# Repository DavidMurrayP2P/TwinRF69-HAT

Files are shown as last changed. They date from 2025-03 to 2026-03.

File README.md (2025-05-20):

# TwinRF69: A new wireless inteface option for the Raspberry Pi (Work in Progress)

The Twin RF69 project aims to extend the wireless capabilities of the Raspberry Pi ecosystem into two different frequencies in the sub 1GHz band. The goal of this is to provide a wireless mesh based alternative to WiFi that utilises longer range, lower power but can still talk IP. I've decided to go down the path of creating dedicated hardware after exploring all the viable options. You can read through and look at my dive into the [wireless interface options](WIRELESS_INTERFACE_RESEARCH.md) for the Raspberry Pi.

The current state of this project is that the hardware design and the code in this repository works. We can successfully send packets on the 915MHz and 433MHz band, and the range exceeds that of WiFi. The interfaces do not yet support IP however.

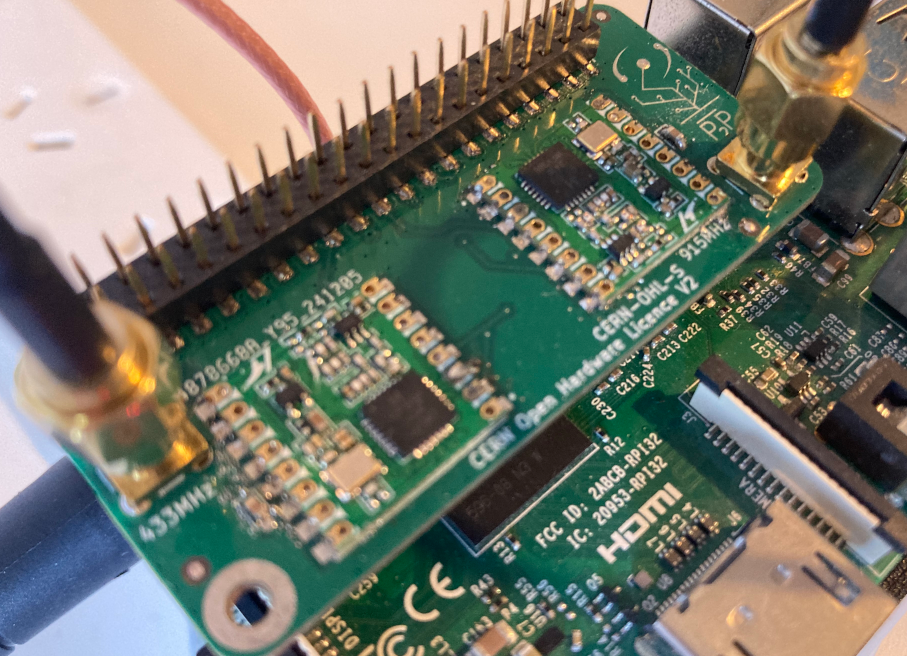
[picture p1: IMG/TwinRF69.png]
 <p style="text-align:center; font-style:italic;">A prototype of the TwinRF69</p>

You can find the user docs, showing you how to get started with the TwinRF69, and the design decisions around the board here:
* [USERDOCS](USERDOCS.md) 
* [DESIGN_AND_DECISIONS](DESIGN_AND_DECISIONS.md)

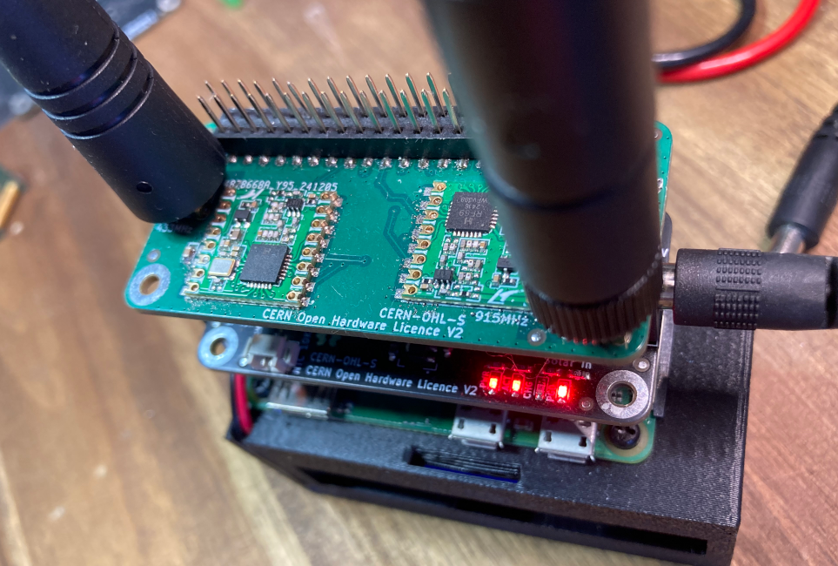
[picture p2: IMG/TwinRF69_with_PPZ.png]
 <p style="text-align:center; font-style:italic;">This project works well with the [Photon Power Zero](https://www.youtube.com/watch?v=qGwqMnN81YI). Both the Photon Power Zero and the TwinRF69  operate as stackable hearders for the Raspberry Pi. This is designed around low power and potentially solar, battery operation and integration with the Photon Power Zero. You can find out more about hit project at the [Photon Power Zero Github](https://github.com/DavidMurrayP2P/PhotonPowerZero/). 

As an open-source project, you can find the code for the Twin RF69, the Kicad PCB files and the FDM 3D printing files below
* [Code](Code)
* [PCBs](PCBs)
* [FDM (3D Print Files)](FDM)

You can find some mounts for Raspberry Pi that include spots for SMA pigtails and power supplies in [FDM (3D Print Files)](FDM)

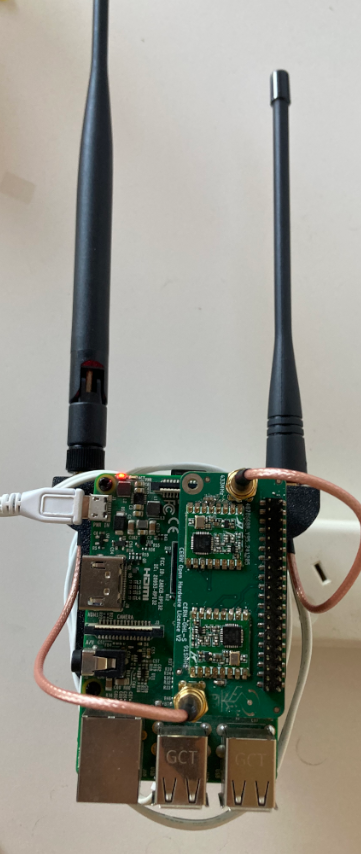
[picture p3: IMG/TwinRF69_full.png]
 <p style="text-align:center; font-style:italic;">A prototype of the TwinRF69</p>

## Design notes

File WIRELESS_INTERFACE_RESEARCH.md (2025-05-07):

# WIRELESS INTERFACE OPTIONS

### This page is incomplete and is a work in progress

This page documents the different Wireless interface options that are avaliable on the Raspberry Pi, obviously going beyond the inbuilt WiFi and Bluetooth. 

As you know the goal of this project is to make it as easy as possible to deply outdoor computing. We want to be able to easily deploy outdoor single board computers and have sensors or cameras report information back. A large comonent of this is networking and having wireless interfaces that ensure that we can collect the data over a wireless interface. 

This page reviews the options and provides the code to make them work. The goal of this project is to make it as easy as possible. We want the network interface to be low power, with a goal of the network interface is to use less than 5V x 0.1 Amps 0.5W on standby and 5V x 0.15 Amps 0.75W while transmitting. With the Raspberry Pi Zero, this means that we are aming fro less than 5v 0.25 Amps total which is 1.25 Watts in total. Going beyond this we will have implications for batteries and solar pannels.

We also want this to be easy. So Ideally, this should be easy to connect to an IP or IPv6 network. I think that the ideal technology in this space, will likely be 6LowPAN. While this has historically been used for 802.15.4 networks it can be used with sme of the Sub-GHz ISM band radios.

Finally, the solution should cost under 40USD. This is not a hard requirement, initially higher costs are tolerable if there is the opportunity for reduced costs in the future with volume.

Speeds should be in the 50-200Kb/s range. The goal is not to stream live video, but we should be at least able to move a 350KB image within 60 seconds. So 350KB is 2800 bytes. If the link supports 50Kb/s then 2800/50 = 56 seconds.

The following is an attempt to evaluate what is currently out there on the market.

## Design Criteria

The goal of this is to provide you with the information you might need if you are deploying a low power solar powered Rasberry Pi Zero. As you can see below, the Raspberry Pi Zero runs at 5V and 0.1 amps which is 0.5W when idle. The design criteria is to stay under 0.2 Amps when Idle and under 0.25 amps when transmitting data. These are my goals for heat and battery life reasons. Be aware that in the [Reducing Energy Consumption](REDUCING_ENERGY_CONSUMPTION.md) document, the power consumption of the Pi Zero 2W was about 25% higher at idle speeds. These are very much ballpark numbers however.

# Options

 - [Cellular Options](#Cellular-Options)
	- [The SIM7600X 4G HAT](#the-sim7600x-4g-hat)
    - [SIMCOM-7020E](#SIMCOM-7020E) NB-IoT
    - [SIMCOM-A7670SA](#SIMCOM-A7670SA) LTE Cat1 Module

 - [LoRaWAN options](#LoRaWAN-Options)
   - [RAK2245](#RAK2245) - Pi HAT 8 Channel LoRaWAN module SX1301
   - [RAK811](#RAK811) LoRaWan End Device

 - [Other Options](#Other-Options)
    - [NRF24](#NRF24)
    - [RFM69HCW](#RFM69HCW)

## Cellular Options

### The SIM7600X 4G HAT

The SIM7600X 4G HAT is a great fit for the Pi. The form factor is great. It appears to work over USB, using spring pins to hit VCC, GND, D+ and D-. You can see the idle power consumption as well as the power consumption under load below. This is a very good module however the price as well as the power consumption are both highert than I would like to see.

Here is the idle power consumption:

Title <p style="text-align:center; font-style:italic;">Raspberry Pi Zero Rough Idle power conspmption </p

#### Config

Check if the Modem is Detected:

```
sudo mmcli -L
```

Enable and Configure the Modem:

```
sudo mmcli -m 0 --enable
sudo mmcli -m 0 --simple-connect="apn=YOUR_APN"
Replace YOUR_APN with your carrier's APN.
```

You can create a new connection using NetworkManager.

```
sudo nmcli connection add type gsm ifname cdc-wdm0 con-name gsm connection.autoconnect yes apn YOUR_APN
```
Connect to the Network:
```
sudo nmcli connection up gsm
```

Once connected, you should see the wwan0 interface with an IP address like below:

Title <p style="text-align:center; font-style:italic;">Raspberry Pi Zero Rough Idle power conspmption </p>

This is the power consumption when lightly loaded.

Title <p style="text-align:center; font-style:italic;">Raspberry Pi Zero Rough Idle power conspmption </p>

Note that this is just a lot higher than we would ideally like to see. 

Title <p style="text-align:center; font-style:italic;">Raspberry Pi Zero Rough Idle power conspmption </p>

### SIMCOM-7020E

This looked exceptionally convenient as the form factor was already Raspberry Pi Zero sided and the headers matched up, eliminating any wiring. I had hoped that this might just work with regular sim card but unfortuately this needs an NB-IoT specialised sim card.

Title <p style="text-align:center; font-style:italic;">The power consumption of the SIMCOM-7020E</p>

### SIMCOM-A7670SA 
##### LTE Cat1 Module

I was excited to try this device because it was sold as supporting LTE Cat 1, but this did not recognise a regular sim. I will keep investigating this module but an initial look did not seem promising. This also only supported serial communications.

This did not work with my regular cheap phone sim.

Setup is pretty simple

```sudo raspi-config```

Navigate to Interfacing Options -> Serial. When prompted, select No to disable the serial console, then select Yes to enable the serial port hardware.

```sudo apt install minicom```

On the serial, try a:

```AT```

Then test if a SIM card has been inserted and detected:

```AT+CPIN?```

This will confirm that the modem is responding. Then: 

```AT+CGDCONT=1,"IP","telstra.m2m"```

Enable the network connection:

```AT+CIICR```

Get the IP address assigned to the module:

```AT+CIFSR```

![Alt text](img/Wireless_Interfaces/SIMA7670SA.png?raw=true "Title") <p style="text-align:center; font-style:italic;">The power consumption of the SIMCOM-A7670SA </p>

## LoRaWAN Options

### RAK2245
##### Pi HAT 8 Channel LoRaWAN module SX1301

I ran a Chiprstack Gatway in hot conditions for many years. I powered this device you can see below with a cheap Ali Express style PoE to usb power plug. 

This is the power consumption after booting:

![Alt text](img/Wireless_Interfaces/RAK2245.png?raw=true "Title") <p style="text-align:center; font-style:italic;">The Raspberry Pi Zero is underneath this RAK2224 concentrator.

This RAK2245 worked very well for long periods of time using the Chirpstack Gateway software. You can check out the latest versions here: https://www.chirpstack.io/docs/chirpstack-gateway-bridge/install/raspberry-pi.html This is a concentrator and will act as a LoRaWAN gateway for your deployment of LoRa devices. 

I genuinely had success with this device but when using this device I wal powering it through A PoE to USB plug similar to this: https://www.aliexpress.com/item/33035428356.html

This is a reasonable option for those wanting a Pi and a LoRaWAN gateway but the power draw is too high for solar and battery with the Photon Power Zero.

### RAK811

These LoRa end device modules work very well. I have had over 4km of reliable  transmit range using these. They do not consume excessive power and they were relatively cheap to buy. These seemed to be well designed and I could move binary data over these modules. The issue is that they are limited in speed by bothe technology, the LoRa standard operates down to vely impressive sensitiviy limits. Furthermore, they are also limited by regulation and in many parts of the world, these devices suffer from duty cycle limits. 

While adhereing to Australian limits, we have slowly moved heavily compressed images over these devices, it's not possible in most parts of the world and these will not be faste enough for a real network inteface in Linux, one of the original goals.

![Alt text](img/Wireless_Interfaces/RAK811_pHAT.png?raw=true "Title") <p style="text-align:center; font-style:italic;">Raspberry Pi Zero Rough Idle power conspmption </p>

## Other Options

### NRF24

The NRF24L01+ is amazingly cheap on places like AliExpress and seems like a great option. 

To get this going you are going to need to wire this up: 

![Alt text](img/Wireless_Interfaces/nrf24.png?raw=true "Title") <p style="text-align:center; font-style:italic;">Raspberry Pi Zero Rough Idle power conspmption </p>

We also want to enable the SPI interface, by running:

```
sudo raspi-config
```

Then enable the SPI interface.

Install the correct libraries

```
sudo apt-get update
sudo apt-get install python3-pip python3-dev libboost-python-dev libboost-thread-dev git
cd RF24
./configure
make
sudo make install
cd pyRF24
sudo python3 setup.py install
```

If you get an error message about not finding lib_boost. Then:  
  
 ```
 sudo find / -name "libboost_python*.so*"
 ```

Find the name and then create a symbolic link. Create a link from your specific lib boost to something more generic:

```
sudo ln -s /usr/lib/arm-linux-gnueabihf/libboost_python311.so /usr/lib/arm-linux-gnueabihf/libboost_python3.so
```
Then try to install again:
```
sudo python3 setup.py install
```

This is the reciever code:
```
from RF24 import *
from time import sleep

# Setup for Raspberry Pi
radio = RF24(25, 0)  # CE is connected to GPIO 25 (Pin 22), CSN to SPI0 CE0 (Pin 24)

def setup():
    if not radio.begin():
        print("Radio hardware not responding")
        return False
    radio.setPALevel(RF24_PA_MIN)
    radio.setDataRate(RF24_1MBPS)
    radio.setCRCLength(RF24_CRC_16)
    radio.openReadingPipe(1, 0xF0F0F0F0E1)
    radio.startListening()
    print("Radio successfully initialized")
    return True

def receive():
    while True:
        if radio.available():
            while radio.available():
                message = radio.read(32)
            print("Received message: {}".format(message.decode('utf-8')))
        else:
            print("No message received")
        sleep(1)

if __name__ == "__main__":
    if setup():
        radio.printDetails()
        receive()
```

This is the trasmitter code:

```
import spidev
from RF24 import *
from time import sleep

# Setup for Raspberry Pi
radio = RF24(25, 0)  # CE is connected to GPIO 25 (Pin 22), CSN to SPI0 CE0 (Pin 24)

def setup():
    # Set SPI speed using spidev
    spi = spidev.SpiDev()
    spi.open(0, 0)  # Open SPI bus 0, device (CS) 0
    spi.max_speed_hz = 500000  # Set SPI speed to 500 kHz
    spi.close()

    print("Initializing the radio...")
    if not radio.begin():
        print("Radio hardware not responding")
        return False
    radio.setPALevel(RF24_PA_MIN)
    radio.setDataRate(RF24_1MBPS)
    radio.setCRCLength(RF24_CRC_16)
    radio.openWritingPipe(0xF0F0F0F0E1)
    radio.stopListening()
    print("Radio successfully initialized")
    return True

def transmit():
    counter = 0
    while True:
        message = f'Hello {counter}'.encode('utf-8')
        print(f"Sending message: {message.decode('utf-8')}")
        result = radio.write(message)
        if result:
            print("Message sent successfully")
        else:
            print("Message sending failed")
        counter += 1
        sleep(1)

if __name__ == "__main__":
    if setup():
        radio.printDetails()
        transmit()
```

![Alt text](img/Wireless_Interfaces/nrf_load.png?raw=true "Title") <p style="text-align:center; font-style:italic;">NRF24 module transmitting</p>

Overall this module is very cheap and low power. There are however, a few issues. Firstly it uses the 2.4GHz band, which is also used by the WiFi Module so there will potentially be some inteference issues using both at the same time in nearby proximiyt.. Secondly, the trasmission difference is not dissimilar from the onboard WiFi. There is no evidence that we it will be possible to reach the a 1km distance. Finally, on the raspberry Pi, it does not enumerate as a network interface. While it might be possible to create a driver that might create a 6LowPAN style interface on the Pi, the  nRF24L01+ only supports payload sizes up to 32 bytes. To make something that can reach a minimum efficiency requirement, the minimum fram size should be 127 octets. This is what 802.15.4 allows.

## RFM69HCW

This module is currently being tested. 

You need to ensure thta you have enabled SPI in the raspberry pi

```sudo raspi-config```

Got to interface options -> Enable SPI

Here is some sample code to test the RFM69HCW after it has been wired:

You can use the code from this repo: https://github.com/etrombly/RFM69

```
#!/usr/bin/env python3

import RFM69
from RFM69registers import *
import datetime
import time

NODE = 1
OTHERNODE = 2
NET = 1
KEY = "1234567890123456"
TIMEOUT = 5
TOSLEEP = 0.1

radio = RFM69.RFM69(RF69_915MHZ, NODE, NET, True)
print("class initialized")

#print("reading all registers")
#results = radio.readAllRegs()
#for result in results:
#    print(result)

print("Performing rcCalibration")
radio.rcCalibration()

print("setting high power")
radio.setHighPower(True)
#radio.setPowerLevel(0)

print("Checking temperature")
print(radio.readTemperature(0))

print("setting encryption")
radio.encrypt(KEY)

radio.setFrequency(915000000)

radio.writeReg(REG_BITRATEMSB, RF_BITRATEMSB_1200)
radio.writeReg(REG_BITRATELSB, RF_BITRATELSB_1200)

radio.writeReg(REG_FDEVMSB, RF_FDEVMSB_5000)
radio.writeReg(REG_FDEVLSB, RF_FDEVLSB_5000)

print("starting loop...")
sequence = 0
try:
    while True:
        msg = "0000000000111111111122222222223333333333444444444455555555556" ##%d : %d" % (NODE, sequence)
        sequence += 1

        print(f"TX >> {OTHERNODE}: {msg}")
        if radio.sendWithRetry(OTHERNODE, msg, 3, 500):
            print("ACK received")

        print("receiving...")
        radio.receiveBegin()
        timedOut = 0
        while not radio.receiveDone():
            timedOut += TOSLEEP
            time.sleep(TOSLEEP)
            if timedOut > TIMEOUT:
                print("nothing received")
                break

        if timedOut <= TIMEOUT:
            sender = radio.SENDERID
            msg = "".join([chr(letter) for letter in radio.DATA])
            ackReq = radio.ACKRequested()
            print(f"RX << {sender}: {msg} (RSSI: {radio.RSSI})")
            if ackReq:
                print("sending ACK...")
                time.sleep(0.05)
                radio.sendACK()
            time.sleep(TIMEOUT / 2)
except KeyboardInterrupt:
    # Clean up properly to not leave GPIO/SPI in an unusable state
    pass

print("shutting down")
radio.shutdown()

```

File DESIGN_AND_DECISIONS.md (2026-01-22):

# Design and Decisions

This document describes the fundamental design decisions of the TwinRF69.

The goal of the project is to pursue a radio technology that provides greater range than regular Pi 2.4GHz WiFi chips, but equally to support higher transimission rates than those found in LoRa transmitters. Re-using a technology that could also be built for less than $10 USD was important.

At the moment, the best current plan is to use adual RF chip design, using the RFM69 chip, which can be bought in 433, and 868/915 MHz variants. At present the technology works and it is possible to successfully send and recieve on both chips.

The next step is to see if it is possible to make this technology talk IP. One of the considerations is to see if it is possible to make it talk IP by linking it to a tun interface on linux.

There are a few possible approaches for how we use the dual band radios to create one low bandwith IP link:
 * Initally it was planned to use the lower band, the 433 MHz band for route discovery and for acknowledgements. The higher frequency, the 868/915MHz band would used for the transmission of data frames. While there is something nice about this approach there is an alterative.
 * An alternate is to say that this link will always be too low bandwidth to be multi hop in any way, at least for IP data. In this case we could just simplify and say that all links were point to point and to negotiate an up and down band. So in this case, ona single node, one radio is always listening and the other is always in sending mode.

Initally, lets just try to support a udp telnet session or a ping over this link.

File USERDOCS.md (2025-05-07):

# User Documentation of the TwinRF69

Make sure that you install RPi.GPIO and spidev with:

    sudo apt install python3-rpi.gpio python3-spidev

Then open:

    raspi-config

Ensure you enable SPI. Then save and reboot.

Also, you will need to ensure that you swap the names of NODE and OTHER node in one of the two TwinRF69_test.py files.

Now, we have made the decision to build  basned on a TUN or IP based interface and to utlise 6LoWPAN and an IPv6 stack.

Let's setup an interface:

    sudo ip tuntap add dev tun0 mode tun
    sudo ip link set dev tun0 up
    sudo ip addr add 2001:db8::1/64 dev tun0
    sudo sysctl -w net.ipv6.conf.all.forwarding=1

Obviously you will need to change the userspace portion of the IPv6 interface for each  network adapter.

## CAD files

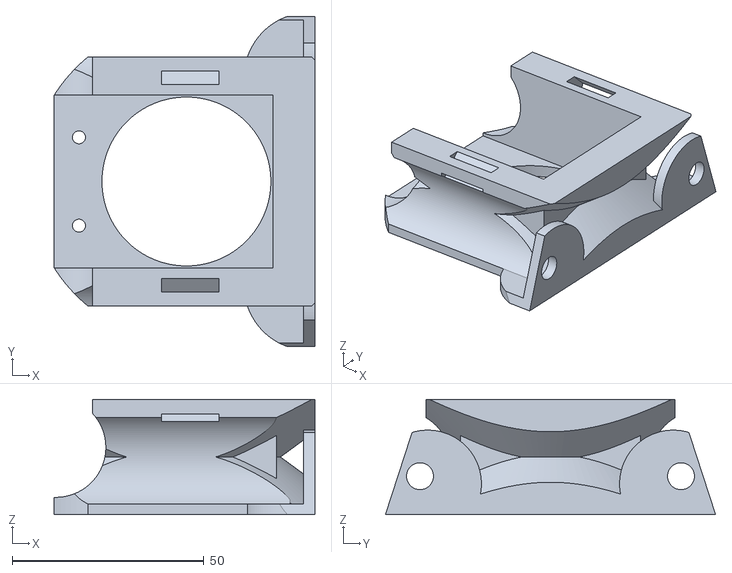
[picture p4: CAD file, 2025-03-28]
FDM/Pi_Wall_wart_Mount_with_SMA_mounts.stl
68.0 x 86.0 x 30.0

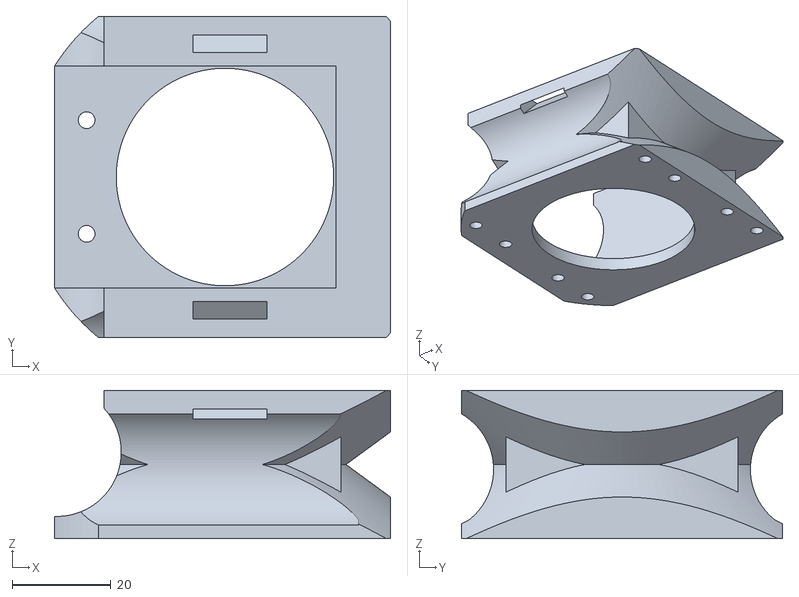
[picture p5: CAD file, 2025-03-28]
FDM/Pi_Wall_wart_Mount.stl
68.0 x 65.0 x 30.0

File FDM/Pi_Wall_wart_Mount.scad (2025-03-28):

difference(){
union() {
//translate([0,0,0])cube([65,58,35], center=true);
translate([0,0,2]) rotate([0,0,0])   cylinder(h=30, r1=42, r2=42, center=true,$fn=128);
translate([30,0,2])cube([7,65,30], center=true);

}

difference() {
translate([-2,0,2]) rotate([0,0,0])   cylinder(h=30, r1=47.5, r2=47.5, center=true,$fn=128);
translate([-5,0,2]) rotate([0,0,0])   cylinder(h=30, r1=8, r2=49, center=true,$fn=128);
translate([-5,0,2]) rotate([0,0,0])   cylinder(h=30, r1=49, r2=8, center=true,$fn=128);
}

    //Space for wall wart
    translate([-9,0,4])cube([61,45,27], center=true);
    
    //Pi Zero holes  
    #translate([29,11.5,-12])rotate([0,0,0])   cylinder(h=5.2, r1=1.7, r2=1.7, center=true,$fn=24);
    translate([-29,11.5,-12])rotate([0,0,0])   cylinder(h=5.2, r1=1.7, r2=1.7, center=true,$fn=24);
    translate([29,-11.5,-12])rotate([0,0,0])   cylinder(h=5.2, r1=1.7, r2=1.7, center=true,$fn=24);
    translate([-29,-11.5,-12])rotate([0,0,0])   cylinder(h=5.2, r1=1.7, r2=1.7, center=true,$fn=24);
    
    //Pi 3B/4/5 holes  
    translate([29,24.5,-12])rotate([0,0,0])   cylinder(h=5.2, r1=1.7, r2=1.7, center=true,$fn=24);
    translate([-29,24.5,-12])rotate([0,0,0])   cylinder(h=5.2, r1=1.7, r2=1.7, center=true,$fn=24);
    translate([29,-24.5,-12])rotate([0,0,0])   cylinder(h=5.2, r1=1.7, r2=1.7, center=true,$fn=24);
    translate([-29,-24.5,-12])rotate([0,0,0])   cylinder(h=5.2, r1=1.7, r2=1.7, center=true,$fn=24);
    
    // Power Supply air flow
    translate([-1,0,0]) rotate([0,0,0])   cylinder(h=68, r1=22, r2=22, center=true,$fn=128);
    //translate([0,0,3]) rotate([0,90,0])   cylinder(h=80, r1=13, r2=13, center=true,$fn=128);
    

    //Slots for velcro ties
    translate([0,-24,20]) rotate([0,45,-90]) cube([30,15,2.5], center=true);
    translate([0,24,20]) rotate([0,45,90]) cube([30,15,2.5], center=true);
    
    //Reduce size
    translate([0,46,0])cube([70,27,60], center=true);
    translate([0,-46,0])cube([70,27,60], center=true);
    translate([45,0,0])cube([25,90,60], center=true);
    translate([-48,0,0])cube([25,70,60], center=true);
    translate([-38,0,20])cube([25,70,40], center=true);
    
    //Space for cable
    translate([-6,-39,1]) rotate([0,90,0])   cylinder(h=64, r1=13, r2=13,center=true,$fn=128);
    translate([-6,39,1]) rotate([0,90,0])   cylinder(h=64, r1=13, r2=13, center=true,$fn=128);
    translate([-35,0,4.5]) rotate([90,0,0])   cylinder(h=70, r1=13, r2=13, center=true,$fn=128);

}

translate([22,0,3])cube([1,47,25], center=true);
translate([2,23,3])cube([40,1,25], center=true);
translate([2,-23,3])cube([40,1,25], center=true);

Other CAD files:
FDM/Pi_Wall_wart_Mount_with_SMA_mounts.scad

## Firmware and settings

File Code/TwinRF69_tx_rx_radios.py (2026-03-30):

#!/usr/bin/env python3

import RFM69
from RFM69registers import *
import time
import RPi.GPIO as GPIO
import os
import fcntl
import struct
import subprocess
from typing import Optional, Union, IO
import errno

#You must set these two variables

REGION = 1 # Set to 1 for 433/915 and 2 for 433/868
NODE_ID = 1 #Set this to an integer between 0 and 9
OTHERNODE = 2
NETWORK_ID = 0
TOSLEEP = 0.064
TIMEOUT = 1

_rx_buffers = {}
_rx_timestamps = {}

class RegionNotSetError(Exception):
    """Please set the appropriate region"""
    pass

def setup_radios(MODULE, FREQUENCY, NODE_ID, NETWORK_ID, INT_PIN, RST_PIN, SPI_BUS, SPI_DEV):

    radio = RFM69.RFM69(
        freqBand=MODULE,
        nodeID=NODE_ID,
        networkID=NETWORK_ID,
        isRFM69HW=True,
        intPin=INT_PIN,
        rstPin=RST_PIN,
        spiBus=SPI_BUS,
        spiDevice=SPI_DEV
    )

    print("Class initialized")

    print("Reading all registers")
    results = radio.readAllRegs()
    for result in results:
        print(result)

    print("Performing rcCalibration")
    radio.rcCalibration()

    print("Setting high power")
    radio.setHighPower(True)
    radio.setPowerLevel(31)

    print("Checking temperature")
    print(radio.readTemperature(0))

    # Accept packets addressed to any node ID — needed so the TX radio can
    # receive ACK frames that may be addressed to the remote node's ID.
    radio.promiscuous(True)

    radio.setFrequency(FREQUENCY)

    # Bitrate: 250 kbps
    radio.writeReg(REG_BITRATEMSB, RF_BITRATEMSB_250000)
    radio.writeReg(REG_BITRATELSB, RF_BITRATELSB_250000)

    # FIX 1 — Gaussian BT=0.5 shaping: tightens TX spectrum, improves sensitivity ~1-2 dB.
    # Was RF_DATAMODUL_MODULATIONSHAPING_00 (no shaping).
    radio.writeReg(REG_DATAMODUL,
                   RF_DATAMODUL_DATAMODE_PACKET |
                   RF_DATAMODUL_MODULATIONTYPE_FSK |
                   RF_DATAMODUL_MODULATIONSHAPING_01)

    # FIX 2 — Fdev = 75 kHz: modulation index h = 2*75k/250k = 0.6 (must be >= 0.5).
    # Previous RF_FDEVMSB/LSB_50000 gave h=0.4 — too low, partial eye closure.
    # 75000 Hz / 61.03515625 Hz/step = 0x04D0
    radio.writeReg(REG_FDEVMSB, 0x04)
    radio.writeReg(REG_FDEVLSB, 0xD0)

    # FIX 3 — RxBw = 200 kHz: must satisfy RxBw >= Fdev + BitRate/2 = 75k + 125k = 200 kHz.
    # Library default was MANT_16|EXP_2 = 125 kHz — too narrow, the main cause of
    # constant CRC failures and corrupted packets.
    # MANT_20|EXP_1 -> 32e6 / (20 * 2 * 4) = 200 kHz.
    radio.writeReg(REG_RXBW,
                   RF_RXBW_DCCFREQ_010 |
                   RF_RXBW_MANT_20 |
                   RF_RXBW_EXP_1)

    # FIX 4 — AfcBw = 400 kHz: AFC bandwidth must be wider than RxBw to lock on
    # during the preamble. Was never set — defaulted to ~83 kHz, causing the AFC
    # to pull the LO the wrong direction on weak signals.
    # MANT_20|EXP_0 -> 32e6 / (20 * 1 * 4) = 400 kHz.
    # REG_AFCBW = 0x1A
    radio.writeReg(0x1A,
                   RF_RXBW_DCCFREQ_010 |
                   RF_RXBW_MANT_20 |
                   RF_RXBW_EXP_0)

    # FIX 5 — DC-free whitening: prevents long 0/1 runs from drifting the receiver's
    # DC baseline at 250 kbps. Was DCFREE_OFF.
    radio.writeReg(REG_PACKETCONFIG1,
                   RF_PACKET1_FORMAT_VARIABLE |
                   RF_PACKET1_DCFREE_WHITENING |
                   RF_PACKET1_CRC_ON |
                   RF_PACKET1_CRCAUTOCLEAR_ON |
                   RF_PACKET1_ADRSFILTERING_OFF)

    # Arm the receiver
    radio.receiveBegin()

    print(f"Radio ready: freq={FREQUENCY/1e6:.3f}MHz  Fdev=75kHz  RxBw=200kHz  AfcBw=400kHz  BR=250kbps")

    return radio

def setup_radios1(MODULE, FREQUENCY, NODE_ID, NETWORK_ID, INT_PIN, RST_PIN, SPI_BUS, SPI_DEV):

    # Initialize the 915MHz radio
    radio = RFM69.RFM69(
        freqBand=MODULE,  # Frequency band
        nodeID=NODE_ID,           # Node ID
        networkID=NETWORK_ID,         # Network ID5
        isRFM69HW=True,        # High-power version flag
        intPin=INT_PIN,             # Custom interrupt pin
        rstPin=RST_PIN,             # Custom reset pin
        spiBus=SPI_BUS,              # Custom SPI bus
        spiDevice=SPI_DEV            # Custom SPI device
    )

    print("Class initialized")

    print("Reading all registers")
    results = radio.readAllRegs()
    for result in results:
        print(result)

    print("Performing rcCalibration")
    radio.rcCalibration()

    print("Setting high power")
    radio.setHighPower(True)
    radio.setPowerLevel(31)

    print("Checking temperature")
    print(radio.readTemperature(0))

    radio.setFrequency(FREQUENCY)
    radio.writeReg(REG_BITRATEMSB, RF_BITRATEMSB_250000)
    radio.writeReg(REG_BITRATELSB, RF_BITRATELSB_250000)
    radio.writeReg(REG_FDEVMSB, RF_FDEVMSB_50000)
    radio.writeReg(REG_FDEVLSB, RF_FDEVLSB_50000)

    return(radio)

def create_tun_for_node(node_id: int,
                        ifname: str = None,
                        network_base: str = "10.0.0",
                        prefix: int = 24):
    """
    Create a TUN device and assign it an IP based on node_id.
    Example: node_id=1 -> IP 10.0.0.1

    Parameters:
      node_id (int): Node id (1..254 recommended).
      ifname (str|None): Interface name to request (e.g. "tun0"). If None, defaults to "tun{node_id}".
      network_base (str): First three octets of network, e.g. "10.0.0".
      prefix (int): CIDR prefix length (default 24).
    
    Returns:
      tuple: (fileobj, ifname, ip_address) where fileobj is the opened /dev/net/tun file object.
    
    Raises:
      PermissionError: if not run as root.
      ValueError: if node_id out of expected range.
      CalledProcessError: if 'ip' commands fail.
    """

    if os.geteuid() != 0:
        raise PermissionError("create_tun_for_node must be run as root (or with CAP_NET_ADMIN)")

    if not (1 <= node_id <= 254):
        raise ValueError("node_id should be between 1 and 254")

    print("The node id is: " + str(node_id))

    if ifname is None:
        ifname = f"tun{node_id}"

    ip_addr = f"{network_base}.{node_id}"
    cidr = f"{ip_addr}/{prefix}"

    # Open tun device
    TUN_DEVICE = "/dev/net/tun"
    tun = open(TUN_DEVICE, "r+b", buffering=0)

    # Constants for ioctl (Linux)
    IFF_TUN = 0x0001
    IFF_NO_PI = 0x1000
    # TUNSETIFF from <linux/if_tun.h>; common value on Linux x86_64
    TUNSETIFF = 0x400454ca

    # Prepare ifreq structure: 16-byte name + short flags (padding to 40 bytes)
    ifreq = struct.pack("16sH", ifname.encode("utf-8"), IFF_TUN | IFF_NO_PI)
    # ioctl to create/configure the interface
    fcntl.ioctl(tun, TUNSETIFF, ifreq)

    # Use iptool to assign address and bring interface up. Use 'replace' to avoid errors if already present.
    subprocess.check_call(["ip", "addr", "replace", cidr, "dev", ifname])
    subprocess.check_call(["ip", "link", "set", "dev", ifname, "up"])
    subprocess.check_call(["ip", "link", "set", "dev", ifname, "mtu", "256"])
    
    return tun, ifname, ip_addr

def read_tun_nonblocking(tun: Union[IO, int], bufsize: int = 4096) -> Optional[bytes]:
    """
    Non-blocking read from a TUN device.

    Parameters:
      tun: file-like object (opened /dev/net/tun) or integer file descriptor.
      bufsize: maximum number of bytes to read (default 4096).

    Returns:
      bytes containing the packet if available, otherwise None.

    Notes:
      - The function will set O_NONBLOCK on the file descriptor if it's not already set.
      - Caller must keep the tun file object open while using this function.
      - Typical usage: pass the file object returned by create_tun_for_node().
    """
    fd = tun.fileno() if hasattr(tun, "fileno") else int(tun)

    # Ensure non-blocking
    flags = fcntl.fcntl(fd, fcntl.F_GETFL)
    if not (flags & os.O_NONBLOCK):
        fcntl.fcntl(fd, fcntl.F_SETFL, flags | os.O_NONBLOCK)

    try:
        return os.read(fd, bufsize)
    except BlockingIOError:
        # No data available right now
        return None
    except OSError as e:
        if e.errno in (errno.EAGAIN, errno.EWOULDBLOCK):
            return None
        raise

def send_packet(pkt: bytes, radio, OTHERNODE: int, chunk_size: int = 55, pause: float = 0.1) -> None:
    """
    Send the given pkt (bytes) over `radio` to `OTHERNODE` in chunks.

    Protocol:
      - Each payload = 4-byte header + chunk
      - Header = MSGID (uint16 BE), SEQ (uint16 BE)
      - SEQ 1..N = data chunks (starts at 1, not 0, to avoid RFM69 dropping first packet)
      - SEQ == 0xFFFF = END marker; its payload after header is two uint16 BE:
           total_chunks, orig_len
    """

    if not isinstance(pkt, (bytes, bytearray)):
        raise TypeError("pkt must be bytes or bytearray")

    # obtain a msgid if a next_msg_id helper exists in this module
    msgid = None
    try:
        next_msg_fn = globals().get('next_msg_id')
        if callable(next_msg_fn):
            msgid = int(next_msg_fn()) & 0xFFFF
    except Exception:
        msgid = None

    if msgid is None:
        msgid = int(time.time() * 1000) & 0xFFFF

    total_len = len(pkt)
    total_chunks = (total_len + chunk_size - 1) // chunk_size

    try:
        for seq in range(total_chunks):
            start = seq * chunk_size
            chunk = pkt[start:start + chunk_size]
            # Use seq+1 so sequence numbers start at 1, not 0 (avoids RFM69 dropping first packet)
            actual_seq = seq + 1
            header = struct.pack(">HH", msgid, actual_seq)  # MSGID, SEQ
            payload = header + chunk

            try:
                radio.send(OTHERNODE, payload)
            except TypeError:
                radio.send(OTHERNODE, list(payload))

            print(f"TX >> {OTHERNODE}: msgid={msgid} seq={actual_seq}/{total_chunks} chunk_len={len(chunk)}")
            time.sleep(pause)

        # send END marker with total_chunks and original length (both uint16 BE)
        end_header = struct.pack(">HH", msgid, 0xFFFF)
        end_payload = end_header + struct.pack(">HH", total_chunks & 0xFFFF, total_len & 0xFFFF)
        try:
            radio.send(OTHERNODE, end_payload)
        except TypeError:
            radio.send(OTHERNODE, list(end_payload))

        print(f"TX >> {OTHERNODE}: msgid={msgid} END total_chunks={total_chunks} orig_len={total_len}")

    except KeyboardInterrupt:
        print("send_packet: interrupted by user")
        raise
    except Exception as e:
        print(f"send_packet: error while sending: {e}")
        raise

def receive_packet_reassemble(radio_rx):
    """
    Non-blocking receive that reassembles fragmented packets.
    Returns (sender_id, reassembled_bytes) when complete, otherwise None.
    """
    global _rx_buffers, _rx_timestamps
    
    if not radio_rx.receiveDone():
        return None
    
    sender_id = radio_rx.SENDERID
    rssi = radio_rx.RSSI
    data = radio_rx.DATA
    
    if isinstance(data, (list, tuple)):
        data_bytes = bytes(data)
    else:
        data_bytes = data
    
    print(f"[RX RAW] {sender_id}: RSSI={rssi} raw_len={len(data_bytes)}")
    
    if len(data_bytes) < 4:
        radio_rx.receiveBegin()
        return None
    
    try:
        msgid, seq = struct.unpack(">HH", data_bytes[:4])
        chunk = data_bytes[4:]
    except Exception as e:
        print(f"[RX ERROR] Failed to parse header: {e}")
        radio_rx.receiveBegin()
        return None
    
    current_time = time.time()
    msg_key = (sender_id, msgid)
    
    # Clean up old messages
    expired_keys = [key for key, ts in _rx_timestamps.items() if current_time - ts > 10.0]
    for key in expired_keys:
        _rx_buffers.pop(key, None)
        _rx_timestamps.pop(key, None)
    
    if msg_key not in _rx_buffers:
        _rx_buffers[msg_key] = {}
        _rx_timestamps[msg_key] = current_time
    
    if seq == 0xFFFF:
        # END marker received
        print(f"[RX END] {sender_id}: msgid={msgid}")
        
        if len(chunk) < 4:
            _rx_buffers.pop(msg_key, None)
            _rx_timestamps.pop(msg_key, None)
            radio_rx.receiveBegin()
            return None
        
        try:
            total_chunks, orig_len = struct.unpack(">HH", chunk[:4])
        except Exception as e:
            _rx_buffers.pop(msg_key, None)
            _rx_timestamps.pop(msg_key, None)
            radio_rx.receiveBegin()
            return None
        
        chunks_received = len(_rx_buffers[msg_key])
        received_seqs = sorted(_rx_buffers[msg_key].keys())
        
        print(f"[RX DEBUG] {sender_id}: msgid={msgid} received {chunks_received}/{total_chunks} chunks: {received_seqs}")
        
        if chunks_received != total_chunks:
            print(f"[RX ERROR] {sender_id}: msgid={msgid} expected {total_chunks}, got {chunks_received}. Dropping.")
            _rx_buffers.pop(msg_key, None)
            _rx_timestamps.pop(msg_key, None)
            radio_rx.receiveBegin()
            return None
        
        # Reassemble chunks in order (seq starts at 1, not 0)
        reassembled = b''
        for i in range(1, total_chunks + 1):
            reassembled += _rx_buffers[msg_key][i]
        
        reassembled = reassembled[:orig_len]
        
        print(f"[RX COMPLETE] {sender_id}: msgid={msgid} reassembled {len(reassembled)} bytes")
        
        _rx_buffers.pop(msg_key, None)
        _rx_timestamps.pop(msg_key, None)
        
        radio_rx.receiveBegin()
        
        # Return the complete packet
        return (sender_id, reassembled)
    
    else:
        # Data chunk
        _rx_buffers[msg_key][seq] = chunk
        print(f"[RX CHUNK] {sender_id}: msgid={msgid} seq={seq} chunk_len={len(chunk)}")
        radio_rx.receiveBegin()
        return None

def main():

    if (REGION == 1):
        print("Entering 433MHz and 915MHz mode")
        MODULE1 = RF69_915MHZ
        FREQUENCY1 = 915000000
    elif (REGION == 2):
        print("Entering 433MHz and 868MHz mode")
        MODULE1 = RF69_868MHZ #Untested
        FREQUENCY1 = 868000000 #Untested
    else:
        raise RegionNotSetError("You have not defined a region. Exiting program.")

    # Constants for configuration
    MODULE0 = RF69_433MHZ
    FREQUENCY0 = 433000000

    packet_size = 62

    tun_file, ifname, ip = create_tun_for_node(NODE_ID)
    print(ifname, ip)

    try:
        
        if NODE_ID == 1: 
            tx_radio = setup_radios(MODULE0, FREQUENCY0, NODE_ID, NETWORK_ID, 16, 15, 0, 0) 
            rx_radio = setup_radios(MODULE1, FREQUENCY1, NODE_ID, NETWORK_ID, 18, 22, 0, 1)
        if NODE_ID == 2:
            rx_radio = setup_radios(MODULE0, FREQUENCY0, NODE_ID, NETWORK_ID, 16, 15, 0, 0) 
            tx_radio = setup_radios(MODULE1, FREQUENCY1, NODE_ID, NETWORK_ID, 18, 22, 0, 1)

        while True:

            pkt = read_tun_nonblocking(tun_file)
            if pkt is None:
                pass
            else:
                send_packet(pkt, tx_radio, OTHERNODE, chunk_size=55, pause=0.1)

			# Non-blocking receive (packets from RX - write them to TUN)
            result = receive_packet_reassemble(rx_radio)
            if result is not None:
                sender_id, reassembled_pkt = result
                try:
                    os.write(tun_file.fileno(), reassembled_pkt)
                    print(f"[TUN WRITE] Wrote {len(reassembled_pkt)} bytes from {sender_id}")
                except OSError as e:
                    print(f"[TUN ERROR] Failed to write: {e}")

            time.sleep(TOSLEEP)

    except:
        print("Shutting down RFM69 modules")
        tx_radio.shutdown()
        rx_radio.shutdown()

if __name__ == "__main__":
    main()

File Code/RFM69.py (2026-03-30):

#!/usr/bin/env python3

# Preconfigured for Raspberry Pi
# For Orange Pi, change:
# - import OPi.GPIO (pip install OrangePi.GPIO)
# - spiBus = 1
# - uncomment GPIO.setboard() call and set correct board type

from RFM69registers import *
import spidev
import RPi.GPIO as GPIO
import time

class RFM69(object):
    def __init__(self, freqBand, nodeID, networkID, isRFM69HW = False, intPin = 18, rstPin = 22, spiBus = 0, spiDevice = 0):

        self.freqBand = freqBand
        self.address = nodeID
        self.networkID = networkID
        self.isRFM69HW = isRFM69HW
        self.intPin = intPin
        self.rstPin = rstPin
        self.spiBus = spiBus
        self.spiDevice = spiDevice
        self.intLock = False
        self.mode = ""
        self.promiscuousMode = False
        self.DATASENT = False
        self.DATALEN = 0
        self.SENDERID = 0
        self.TARGETID = 0
        self.PAYLOADLEN = 0
        self.ACK_REQUESTED = 0
        self.ACK_RECEIVED = 0
        self.RSSI = 0
        self.DATA = []
        self.sendSleepTime = 0.05

        #GPIO.setboard(GPIO.ZERO)   # for Orange Pi, see https://pypi.org/project/OrangePi.GPIO/
        GPIO.setmode(GPIO.BOARD)
        GPIO.setup(self.intPin, GPIO.IN)
        GPIO.setup(self.rstPin, GPIO.OUT)

        frfMSB = {RF69_315MHZ: RF_FRFMSB_315, RF69_433MHZ: RF_FRFMSB_433,
                  RF69_868MHZ: RF_FRFMSB_868, RF69_915MHZ: RF_FRFMSB_915}
        frfMID = {RF69_315MHZ: RF_FRFMID_315, RF69_433MHZ: RF_FRFMID_433,
                  RF69_868MHZ: RF_FRFMID_868, RF69_915MHZ: RF_FRFMID_915}
        frfLSB = {RF69_315MHZ: RF_FRFLSB_315, RF69_433MHZ: RF_FRFLSB_433,
                  RF69_868MHZ: RF_FRFLSB_868, RF69_915MHZ: RF_FRFLSB_915}

        self.CONFIG = {
          0x01: [REG_OPMODE, RF_OPMODE_SEQUENCER_ON | RF_OPMODE_LISTEN_OFF | RF_OPMODE_STANDBY],
          #no shaping
          0x02: [REG_DATAMODUL, RF_DATAMODUL_DATAMODE_PACKET | RF_DATAMODUL_MODULATIONTYPE_FSK | RF_DATAMODUL_MODULATIONSHAPING_00],
          #default:4.8 KBPS
          0x03: [REG_BITRATEMSB, RF_BITRATEMSB_4800],
          0x04: [REG_BITRATELSB, RF_BITRATELSB_4800],
          #default:5khz, (FDEV + BitRate/2 <= 500Khz)
          0x05: [REG_FDEVMSB, RF_FDEVMSB_5000],
          0x06: [REG_FDEVLSB, RF_FDEVLSB_5000],

          0x07: [REG_FRFMSB, frfMSB[freqBand]],
          0x08: [REG_FRFMID, frfMID[freqBand]],
          0x09: [REG_FRFLSB, frfLSB[freqBand]],

          # looks like PA1 and PA2 are not implemented on RFM69W, hence the max output power is 13dBm
          # +17dBm and +20dBm are possible on RFM69HW
          # +13dBm formula: Pout=-18+OutputPower (with PA0 or PA1**)
          # +17dBm formula: Pout=-14+OutputPower (with PA1 and PA2)**
          # +20dBm formula: Pout=-11+OutputPower (with PA1 and PA2)** and high power PA settings (section 3.3.7 in datasheet)
          #0x11: [REG_PALEVEL, RF_PALEVEL_PA0_ON | RF_PALEVEL_PA1_OFF | RF_PALEVEL_PA2_OFF | RF_PALEVEL_OUTPUTPOWER_11111],
          #over current protection (default is 95mA)
          #0x13: [REG_OCP, RF_OCP_ON | RF_OCP_TRIM_95],

          # RXBW defaults are { REG_RXBW, RF_RXBW_DCCFREQ_010 | RF_RXBW_MANT_24 | RF_RXBW_EXP_5} (RxBw: 10.4khz)
          #//(BitRate < 2 * RxBw)
          0x19: [REG_RXBW, RF_RXBW_DCCFREQ_010 | RF_RXBW_MANT_16 | RF_RXBW_EXP_2],
          #for BR-19200: //* 0x19 */ { REG_RXBW, RF_RXBW_DCCFREQ_010 | RF_RXBW_MANT_24 | RF_RXBW_EXP_3 },
          #DIO0 is the only IRQ we're using
          0x25: [REG_DIOMAPPING1, RF_DIOMAPPING1_DIO0_01],
          #must be set to dBm = (-Sensitivity / 2) - default is 0xE4=228 so -114dBm
          0x29: [REG_RSSITHRESH, 220],
          #/* 0x2d */ { REG_PREAMBLELSB, RF_PREAMBLESIZE_LSB_VALUE } // default 3 preamble bytes 0xAAAAAA
          0x2e: [REG_SYNCCONFIG, RF_SYNC_ON | RF_SYNC_FIFOFILL_AUTO | RF_SYNC_SIZE_2 | RF_SYNC_TOL_0],
          #attempt to make this compatible with sync1 byte of RFM12B lib
          0x2f: [REG_SYNCVALUE1, 0x2D],
          #NETWORK ID
          0x30: [REG_SYNCVALUE2, networkID],
          0x37: [REG_PACKETCONFIG1, RF_PACKET1_FORMAT_VARIABLE | RF_PACKET1_DCFREE_OFF |
                RF_PACKET1_CRC_ON | RF_PACKET1_CRCAUTOCLEAR_ON | RF_PACKET1_ADRSFILTERING_OFF],
          #in variable length mode: the max frame size, not used in TX
          0x38: [REG_PAYLOADLENGTH, 66],
          #* 0x39 */ { REG_NODEADRS, nodeID }, //turned off because we're not using address filtering
          #TX on FIFO not empty
          0x3C: [REG_FIFOTHRESH, RF_FIFOTHRESH_TXSTART_FIFONOTEMPTY | RF_FIFOTHRESH_VALUE],
          #RXRESTARTDELAY must match transmitter PA ramp-down time (bitrate dependent)
          0x3d: [REG_PACKETCONFIG2, RF_PACKET2_RXRESTARTDELAY_2BITS | RF_PACKET2_AUTORXRESTART_ON | RF_PACKET2_AES_OFF],
          #for BR-19200: //* 0x3d */ { REG_PACKETCONFIG2, RF_PACKET2_RXRESTARTDELAY_NONE | RF_PACKET2_AUTORXRESTART_ON | RF_PACKET2_AES_OFF }, //RXRESTARTDELAY must match transmitter PA ramp-down time (bitrate dependent)
          #* 0x6F */ { REG_TESTDAGC, RF_DAGC_CONTINUOUS }, // run DAGC continuously in RX mode
          # run DAGC continuously in RX mode, recommended default for AfcLowBetaOn=0
          0x6F: [REG_TESTDAGC, RF_DAGC_IMPROVED_LOWBETA0],
          0x00: [255, 0]
        }

        #initialize SPI
        self.spi = spidev.SpiDev()
        self.spi.open(self.spiBus, self.spiDevice)
        self.spi.max_speed_hz = 4000000

        # Hard reset the RFM module
        GPIO.output(self.rstPin, GPIO.HIGH);
        time.sleep(0.1)
        GPIO.output(self.rstPin, GPIO.LOW);
        time.sleep(0.1)

        #verify chip is syncing?
        while self.readReg(REG_SYNCVALUE1) != 0xAA:
            self.writeReg(REG_SYNCVALUE1, 0xAA)

        while self.readReg(REG_SYNCVALUE1) != 0x55:
            self.writeReg(REG_SYNCVALUE1, 0x55)

        #write config
        for value in self.CONFIG.values():
            self.writeReg(value[0], value[1])

        self.encrypt(0)
        self.setHighPower(self.isRFM69HW)
        # Wait for ModeReady
        while (self.readReg(REG_IRQFLAGS1) & RF_IRQFLAGS1_MODEREADY) == 0x00:
            pass

        GPIO.remove_event_detect(self.intPin)
        GPIO.add_event_detect(self.intPin, GPIO.RISING, callback=self.interruptHandler)

    def setFrequency(self, freqHz):
        step = 61.03515625
        freq = int(round(freqHz / step))
        self.writeReg(REG_FRFMSB, freq >> 16)
        self.writeReg(REG_FRFMID, freq >> 8)
        self.writeReg(REG_FRFLSB, freq)

    def getFrequency(self):
        step = 61.03515625
        freq = (self.readReg(REG_FRFMSB) << 16) + (self.readReg(REG_FRFMID) << 8) + self.readReg(REG_FRFLSB)
        return int(round(freq * step))

    def setMode(self, newMode):
        if newMode == self.mode:
            return
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

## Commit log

2025-03-28 Add code
    [Pi_Wall_wart_Mount.scad, Pi_Wall_wart_Mount.stl, Pi_Wall_wart_Mount_with_SMA_mounts.scad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]
2026-04-17 Fix throughput bottlenecks in TwinRF69_tx_rx_radios.py and new.py
    Agent-Logs-Url: https://github.com/DavidMurrayP2P/TwinRF69-HAT/sessions/ef6e54f3-9d59-41ff-8f5a-5f247753d239
    [TwinRF69_tx_rx_radios.py]
2026-04-17 Fix race condition in interruptHandler and remove unused files
    Agent-Logs-Url: https://github.com/DavidMurrayP2P/TwinRF69-HAT/sessions/af292293-c180-4ef6-829a-152e716f5e89
    [RFM69.py]
2026-04-17 Fix RX chunk loss: re-arm receiver immediately after snapshotting data
    Agent-Logs-Url: https://github.com/DavidMurrayP2P/TwinRF69-HAT/sessions/becbe8e2-4c29-4e6b-99b7-8026bfdb21c4
    [TwinRF69_tx_rx_radios.py]
2026-04-17 Fix RX radio missing packets: add receive queue and immediate RX re-arm
    Agent-Logs-Url: https://github.com/DavidMurrayP2P/TwinRF69-HAT/sessions/a77357a3-aa44-46d5-b8be-d7cae1259b62
    [RFM69.py, TwinRF69_tx_rx_radios.py]
2026-04-17 Add seq range validation to reject ghost/corrupt RF packets
    Ghost packets (seq==msgid at values like 2827, 8738, 16448) slip past the
    hardware CRC due to RF interference. Valid data chunks use seq 1..255 and
    the END marker uses seq=0xFFFF. Anything outside that range is discarded
    immediately before entering the reassembly buffer.
    Agent-Logs-Url: https://github.com/DavidMurrayP2P/TwinRF69-HAT/sessions/9b4530ec-75be-4103-8053-f2f6a34758a3
    [TwinRF69_tx_rx_radios.py]
2026-04-17 feat: TX/RX interlock to prevent inter-radio desensitization
    Agent-Logs-Url: https://github.com/DavidMurrayP2P/TwinRF69-HAT/sessions/df915c67-20a3-4b8d-ac5f-36e0ae725d63
    [TwinRF69_tx_rx_radios.py]
2026-04-17 feat: add XOR parity FEC — recover any single lost chunk per message
    Agent-Logs-Url: https://github.com/DavidMurrayP2P/TwinRF69-HAT/sessions/08588ef2-a136-407f-87e7-3aa274dca0e2
2026-04-17 fix review: remove unused chunks list, guard StopIteration, truncate recovered final chunk
    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
    [TwinRF69_tx_rx_radios.py]
